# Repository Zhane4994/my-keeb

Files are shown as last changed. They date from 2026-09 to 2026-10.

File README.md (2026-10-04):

I designed a mechanical keyboard from scratch with kicad pcb's and onshape cases. I also learned how to use the RMK firmware to create a functional keyboard. I did this project because I used to be into keyboards and I thought it would be super cool to not only learn more about how they work but how to design one.

Part I, PCB and Schematic design

Day 1 Hour 1

I’m currently working on this at lunch. I have no idea what I’m doing lmao just following the guide. I have a slight idea of what I want to make. I am going to make it a 75% keyboard with a lcd screen and a knob. I just found out it’s supposedly due in a month golly. LOCK IN. This is my inspiration
nmpc-yunzii-AL80-silver-mechanical-keyboard-2059385894

Day 1 Hour 2

Just got back from school. I’ll be working on this for the next few days hopefully I’m able to get to the coding soon.


Just finished up the schematic matrices mostly.
Screenshot 2026-09-10 at 7 05 09 PM

Just finished up the Schematic matrices

Day 1 Hour 3

Screenshot 2026-09-10 at 7 27 56 PM

WOW. I’ve made up quite a bit of progress already and I’ve already thought of an idea of what I want my keyboard to be like. 1st, I want the entire keyboard to be a normal keyboard with no special shapes and a screen above the arrow keys. Now I’ve begun to create my PCB design.

Day 1 Hour 4&5

I spend 2 hours working on the PCB. I had to restart because I messed up the schematic somehow and it took me a bit to get the layout of the keyboard right. 
Screenshot 2026-09-10 at 11 40 44 PM

Day 1 Hour 6

I’ve just spent one hour on just wiring alone. This is super time consuming
Screenshot 2026-09-11 at 7 28 20 PM

Day 2 Hour 7&8

I’ve spent a while just working on moving stuff around according to the DRC as I had some issues. I also added a Rotary encoder and a OLED screen. I forgot to screenshot yesterday so this is my finished PCB now. I had to rewire a bunch of stuff and the PCB is packed and there isn’t much room.

Day 2 Hour 9

I just began to make my case. It actually took me so long to find out how to get the bom.cvs files
Screenshot 2026-09-11 at 11 09 13 PM

Day 2 Hour 10&11

Spent an hour creating the bottom half of my keyboard case and beginning to map out the key’s
Screenshot 2026-09-12 at 11 47 04 PM

I got through my process and realized that the tab, caps lock, shift, and control keys probably won’t work as I just randomly placed them. This is going to backtrack me all the way to a non wired PCB. Which will be annoying but I think it will be worth it just to get a keycap set that will actually look good on it.

Day 3 Hour 12

I spend this hour mostly asking ai how a led matrix works and if its possible with the pico its actually so bad but now I’m beginning to create the matrix and fixed using the normal GND pin instead of the AGND pin.


Day 3 Hour 13

Spent one hour creating a LED matrix and create the PCB
Screenshot 2026-09-13 at 7 27 45 PM

Day 4 Hour 14

I have spend today so far asking ai what to do about my capacitor situation because the ones I found on Aliexpress don’t have measurements of how apart the legs are and I didn’t think of just bending them if they are too close together so I’m just going to use radial 5mm 
Screenshot 2026-09-14 at 4 22 03 PM

Completed the key switch placement

Day 4 Hour 15&16

Screenshot 2026-09-14 at 7 28 04 PM

JEEZ. This actually took so long. I ended up taking 2 hours just to put in the diodes as well as all the LED in the right position. And I’m just starting wiring. This is going to be super hard and thanks to MD for letting me go off his keyboard as a reference point.

Day 5 Hour 17

Screenshot 2026-09-15 at 6 12 45 PM

So I just found out that I need to set the footprint to a different one for hot swap sockets so now I have to redo all the placements again

Day 5 Hour 18

Screenshot 2026-09-15 at 10 32 31 PM

While looking through the examples in slack, I found out that I don’t actually have enough space for a plate between the pcb and the top of the switches thanks to the pico 😡. Also someone told me that the LED’s actually should be on the bottom layer. AFTER I WIRED THEM ALL. So great I think it will be a lot easier to just straight up restart again 😡

Day 6 Hour 19

Screenshot 2026-09-16 at 5 32 16 PM

I’ve spent today wiring out the PCB. It’s super complicated as I flipped the pico to the back and have to switch the pin locations on the schematic.

Day 7 Hour 20

Screenshot 2026-09-20 at 6 13 34 PM

Pretty much finished my wiring. I took a forced break from my dad yesterday so lost some time there. I will try to complete by Wednesday or at least get to firmware.

Day 7 Hour 21

I’ve finished my PCB and tweaked it halfway into the case design because I realized the resistor placement is not optimal(look up above. I wanted to do a gasket mount by making the inside of the case be under the pcb by 3 mm but a resistor and capacitor would be in the way and I think it would just be better to move them)
I also began my case design so here’s part II
Part II, Case design

Day 9 Hour 22-25

It’s been a couple of days. I forgot to document my process but I’ve been using guides and references and I’ve taken about 3 hours to complete my case.
Screenshot 2026-09-25 at 6 41 36 PM

Day 10 Hour 26

Today, I’ve spent about an hour. Brainstorming and thinking of ideas of how to snap fit the 2 housing parts together and I’ve come up with an idea. Once side will have holes that the top housing can go into with tabs




And on the part of the case away from the user, there will be a notch in the base and a tab that will slide into it
Screenshot 2026-09-26 at 2 42 32 PM



Also It’s a triangle just so its a bit easier to take off but won’t come off just with use.

Screenshot 2026-09-26 at 3 53 06 PM

Completed Case
Part 3, Firmware
Day 11 Hour 27-29
I've spend almost 2 hours looking around the docs and figuring out how this works. The docs were pretty confusing because i have no clue what they are talking about lol
Screenshot 2026-09-26 at 3 53 06 PM
And that is my keyboard complete. I have 2 days left so i'm going to submit asap!
Screenshot 2026-10-02 at 9 41 14 PM

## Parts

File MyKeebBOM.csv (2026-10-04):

Reference | Qty | Value | DNP | Footprint | Datasheet | "Vendor" | "CAD" | "USD"
C1,C3,C4,C5,C6,C7,C8,C9,C10,C11 | 10 | 100 nF |  | Capacitor_THT:C_Radial_D5.0mm_H5.0mm_P2.00mm |  | https://www.aliexpress.com/item/1005005691676032.html
C2 | 1 | 470 uF |  | Capacitor_THT:C_Radial_D5.0mm_H5.0mm_P2.00mm |  | https://www.aliexpress.com/item/1005005945721276.html
R1 | 1 | 330 |  | Resistor_THT:R_Axial_DIN0207_L6.3mm_D2.5mm_P10.16mm_Horizontal |  | https://www.aliexpress.com/item/1005002994755806.html
S1 | 1 | 6.25 |  | PCM_marbastlib-mx:STAB_MX_P_6.25u |  | https://www.gateron.com/products/gateron-pcb-mounted-stabilizer?VariantsId=10538 | 8.54
S2 | 1 | 2.25 |  | PCM_marbastlib-mx:STAB_MX_P_2.25u |  | https://www.gateron.com/products/gateron-pcb-mounted-stabilizer?VariantsId=10538 | 8.54
S3 | 1 | 2.75 |  | PCM_marbastlib-mx:STAB_MX_2.75u |  | https://www.gateron.com/products/gateron-pcb-mounted-stabilizer?VariantsId=10538 | 8.54
S4 | 1 | 2.25 |  | PCM_marbastlib-mx:STAB_MX_2.25u |  | https://www.gateron.com/products/gateron-pcb-mounted-stabilizer?VariantsId=10538 | 8.54
S5 | 1 | 2 |  | PCM_marbastlib-mx:STAB_MX_2u |  | https://www.gateron.com/products/gateron-pcb-mounted-stabilizer?VariantsId=10538 | 8.54
SW1,SW2,SW3,SW4,SW5,SW6,SW7,SW8,SW9,SW10,SW11,SW12,SW13,SW14,SW15,SW16,SW17,SW18,SW19,SW20,SW21,SW22,SW23,SW24,SW25,SW26,SW27,SW29,SW30,SW31,SW32,SW33,SW34,SW35,SW36,SW37,SW38,SW39,SW40,SW43,SW44,SW45,SW46,SW47,SW48,SW49,SW50,SW51,SW52,SW53,SW54,SW55,SW56,SW57,SW58,SW59,SW60,SW61,SW62,SW63,SW64,SW65,SW66,SW67,SW71,SW74,SW75,SW76 | 68 | SW_Push |  | PCM_marbastlib-mx:SW_MX_HS_KS-2P02B01-01_1u |  | https://www.gateron.com/products/gateron-ks-3-milky-pro-switch-set?VariantsId=10404 | 40.7
SW28,SW41 | 2 | SW_Push |  | PCM_marbastlib-mx:SW_MX_HS_KS-2P02B01-01_1.5u |  | https://www.gateron.com/products/gateron-ks-3-milky-pro-switch-set?VariantsId=10404 | 40.7
SW42 | 1 | SW_Push |  | PCM_marbastlib-mx:SW_MX_HS_KS-2P02B01-01_1.75u |  | https://www.gateron.com/products/gateron-ks-3-milky-pro-switch-set?VariantsId=10404 | 40.7
SW68,SW69,SW70,SW72,SW73 | 5 | SW_Push |  | PCM_marbastlib-mx:SW_MX_HS_KS-2P02B01-01_1.25u |  | https://www.gateron.com/products/gateron-ks-3-milky-pro-switch-set?VariantsId=10404 | 40.7
SW78 | 1 | RotaryEncoder_Switch |  | Rotary_Encoder:RotaryEncoder_Alps_EC11E-Switch_Vertical_H20mm_MountingHoles |  | https://www.digikey.ca/en/products/detail/alps-alpine/EC11E15244G1/21721550 | 7.69
D1,D2,D3,D4,D5,D6,D7,D8,D9,D10,D11,D12,D13,D14,D15,D16,D17,D18,D19,D20,D21,D22,D23,D24,D25,D26,D27,D28,D29,D30,D31,D32,D33,D34,D35,D36,D37,D38,D39,D40,D41,D42,D43,D44,D45,D46,D47,D48,D49,D50,D51,D52,D53,D54,D55,D56,D57,D58,D59,D60,D61,D62,D63,D64,D65,D66,D67,D68,D69,D70,D71,D72,D73,D74,D75,D76,D77 | 77 | 1N4148 |  | Diode_THT:D_DO-35_SOD27_P7.62mm_Horizontal | https://assets.nexperia.com/documents/data-sheet/1N4148_1N4448.pdf | https://www.aliexpress.com/item/1005009379098965.html
A1 | 1 | RaspberryPi_Pico |  | Module:RaspberryPi_Pico_Common_THT | https://datasheets.raspberrypi.com/pico/pico-datasheet.pdf | https://www.aliexpress.com/item/1005007385123930.html | 6.19
U1 | 1 | ER_OLEDM0.91_1x-I2C |  | Display:ER_OLEDM0.91_1x-I2C | https://www.buydisplay.com/download/manual/ER-OLEDM0.91-1_Datasheet.pdf | https://www.aliexpress.com/item/1005012376797588.html
D78,D79,D80,D81,D82,D83,D84,D85,D86,D87,D88,D89,D90,D91,D92,D93,D94,D95,D96,D97,D98,D99,D100,D101,D102,D103,D104,D105,D106,D107,D108,D109,D110,D111,D112,D113,D114,D115,D116,D117,D118,D119,D120,D121,D122,D123,D124,D125,D126,D127,D128,D129,D130,D131,D132,D133,D134,D135,D136,D137,D138,D139,D140,D141,D142,D143,D144,D145,D146,D147,D148,D149,D150,D151,D152,D153 | 76 | SK6812MINI-E |  | LED_SMD:LED_SK6812MINI-E_3.2x2.8mm_P1.5mm_ReverseMount | https://www.lcsc.com/datasheet/C5149201.pdf | https://www.lcsc.com/product-detail/C5149201.html?s_z=n_SK6812%2520MINI-E | Not Listed | 5.2
SW1,SW2,SW3,SW4,SW5,SW6,SW7,SW8,SW9,SW10,SW11,SW12,SW13,SW14,SW15,SW16,SW17,SW18,SW19,SW20,SW21,SW22,SW23,SW24,SW25,SW26,SW27,SW29,SW30,SW31,SW32,SW33,SW34,SW35,SW36,SW37,SW38,SW39,SW40,SW43,SW44,SW45,SW46,SW47,SW48,SW49,SW50,SW51,SW52,SW53,SW54,SW55,SW56,SW57,SW58,SW59,SW60,SW61,SW62,SW63,SW64,SW65,SW66,SW67,SW71,SW74,SW75,SW76,SW28,SW41,SW42,SW68,SW69,SW70,SW72,SW73 | 76 | Hotswap Sockets |  |  |  | https://www.gateron.com/products/gateron-hot-swap-pcb-socket?VariantsId=10171 | 15.66
SW1,SW2,SW3,SW4,SW5,SW6,SW7,SW8,SW9,SW10,SW11,SW12,SW13,SW14,SW15,SW16,SW17,SW18,SW19,SW20,SW21,SW22,SW23,SW24,SW25,SW26,SW27,SW29,SW30,SW31,SW32,SW33,SW34,SW35,SW36,SW37,SW38,SW39,SW40,SW43,SW44,SW45,SW46,SW47,SW48,SW49,SW50,SW51,SW52,SW53,SW54,SW55,SW56,SW57,SW58,SW59,SW60,SW61,SW62,SW63,SW64,SW65,SW66,SW67,SW71,SW74,SW75,SW76,SW28,SW41,SW42,SW68,SW69,SW70,SW72,SW73 | 76 | KeyCaps |  |  |  | https://www.aliexpress.com/item/1005010591356090.html | 13

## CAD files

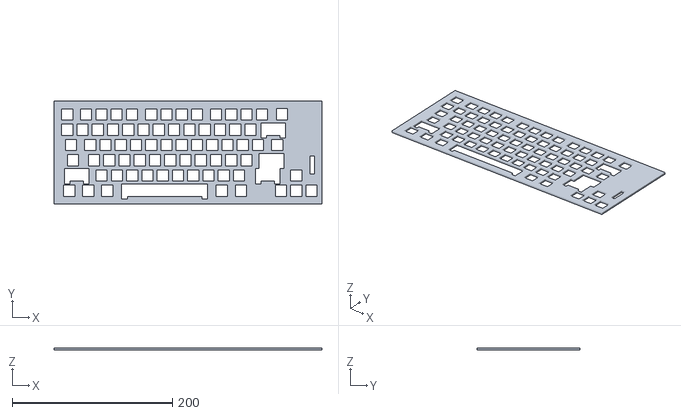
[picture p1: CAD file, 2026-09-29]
MyKeeb Case - Foam Plate(2).stl
334.5 x 128.7 x 2.50

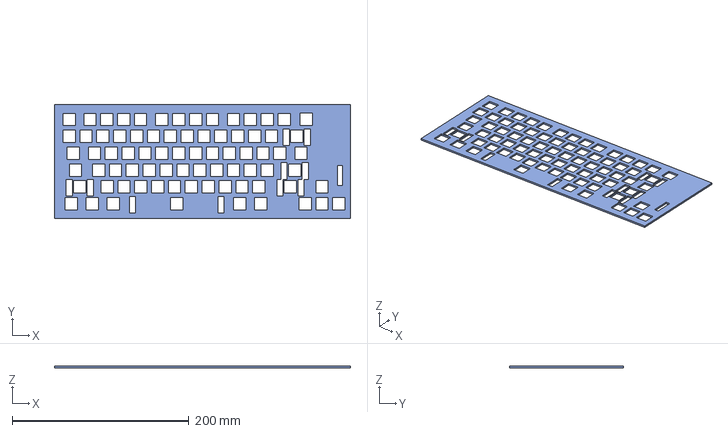
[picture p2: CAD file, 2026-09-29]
STEP files/MyKeeb Case - Plate.step
334.5 x 128.8 x 2.00 mm

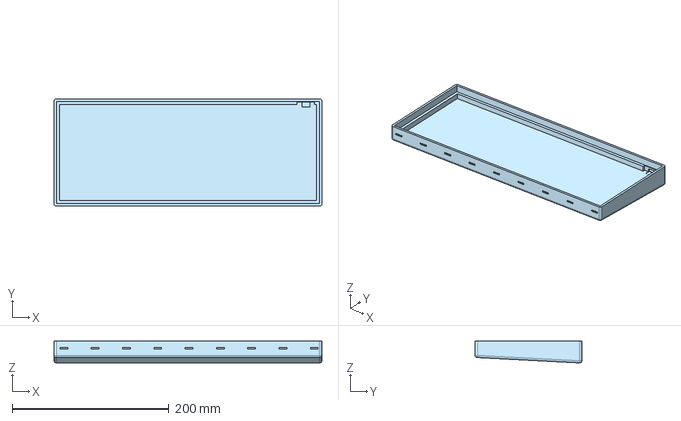
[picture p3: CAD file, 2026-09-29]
STEP files/MyKeeb Case - Base Housing.step
342.5 x 136.8 x 28.0 mm

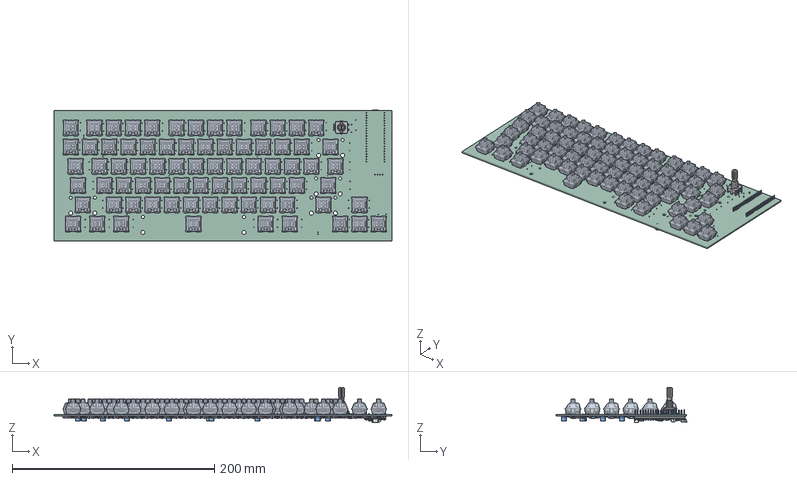
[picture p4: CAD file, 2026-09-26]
MyKeeb.step
334.5 x 129.2 x 34.8 mm
EC11_Rotary_Encoder_Switched
C_Radial_D50mm_H50mm_P200mm x 11
Pin1 x 76
Pin2 x 76
Pin3 x 76
Pin4 x 76
HS_gat_mx v8 x 76
RD-05E35zu19 x 76
D_DO-35_SOD27_P7.62mm_Horizontal x 77
RaspberryPi_Pico_H_Module_KiCad
RaspberryPi_Pico_Header_DIP-40_H2.54mm_KiCad
R_Axial_DIN0207_L63mm_D25mm_P1016mm_Horizontal
MyKeeb_PCB

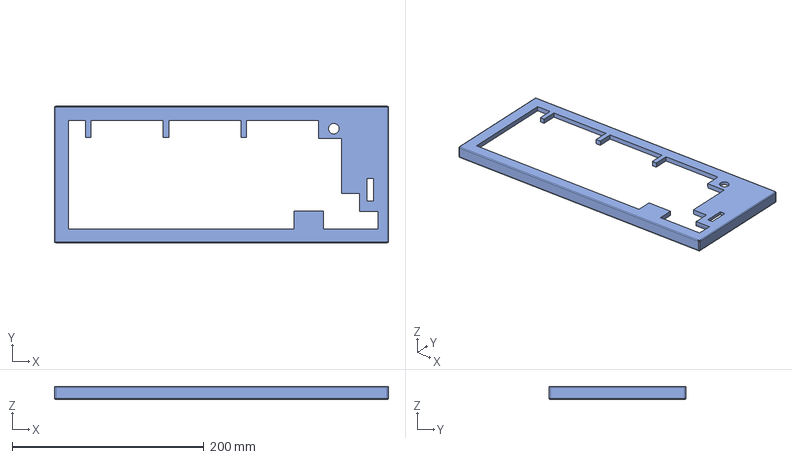
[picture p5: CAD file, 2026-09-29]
STEP files/MyKeeb Case - Top Housing.step
348.5 x 142.8 x 14.0 mm

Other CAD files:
MyKeeb Case - Foam Plate(1).step
STEP files/MyKeeb Case - Foam Plate.step
MyKeeb Case - Plate(1).stl
STL files/MyKeeb Case - Base Housing.stl
STL files/MyKeeb Case - Plate.stl
STL files/MyKeeb Case - Top Housing.stl

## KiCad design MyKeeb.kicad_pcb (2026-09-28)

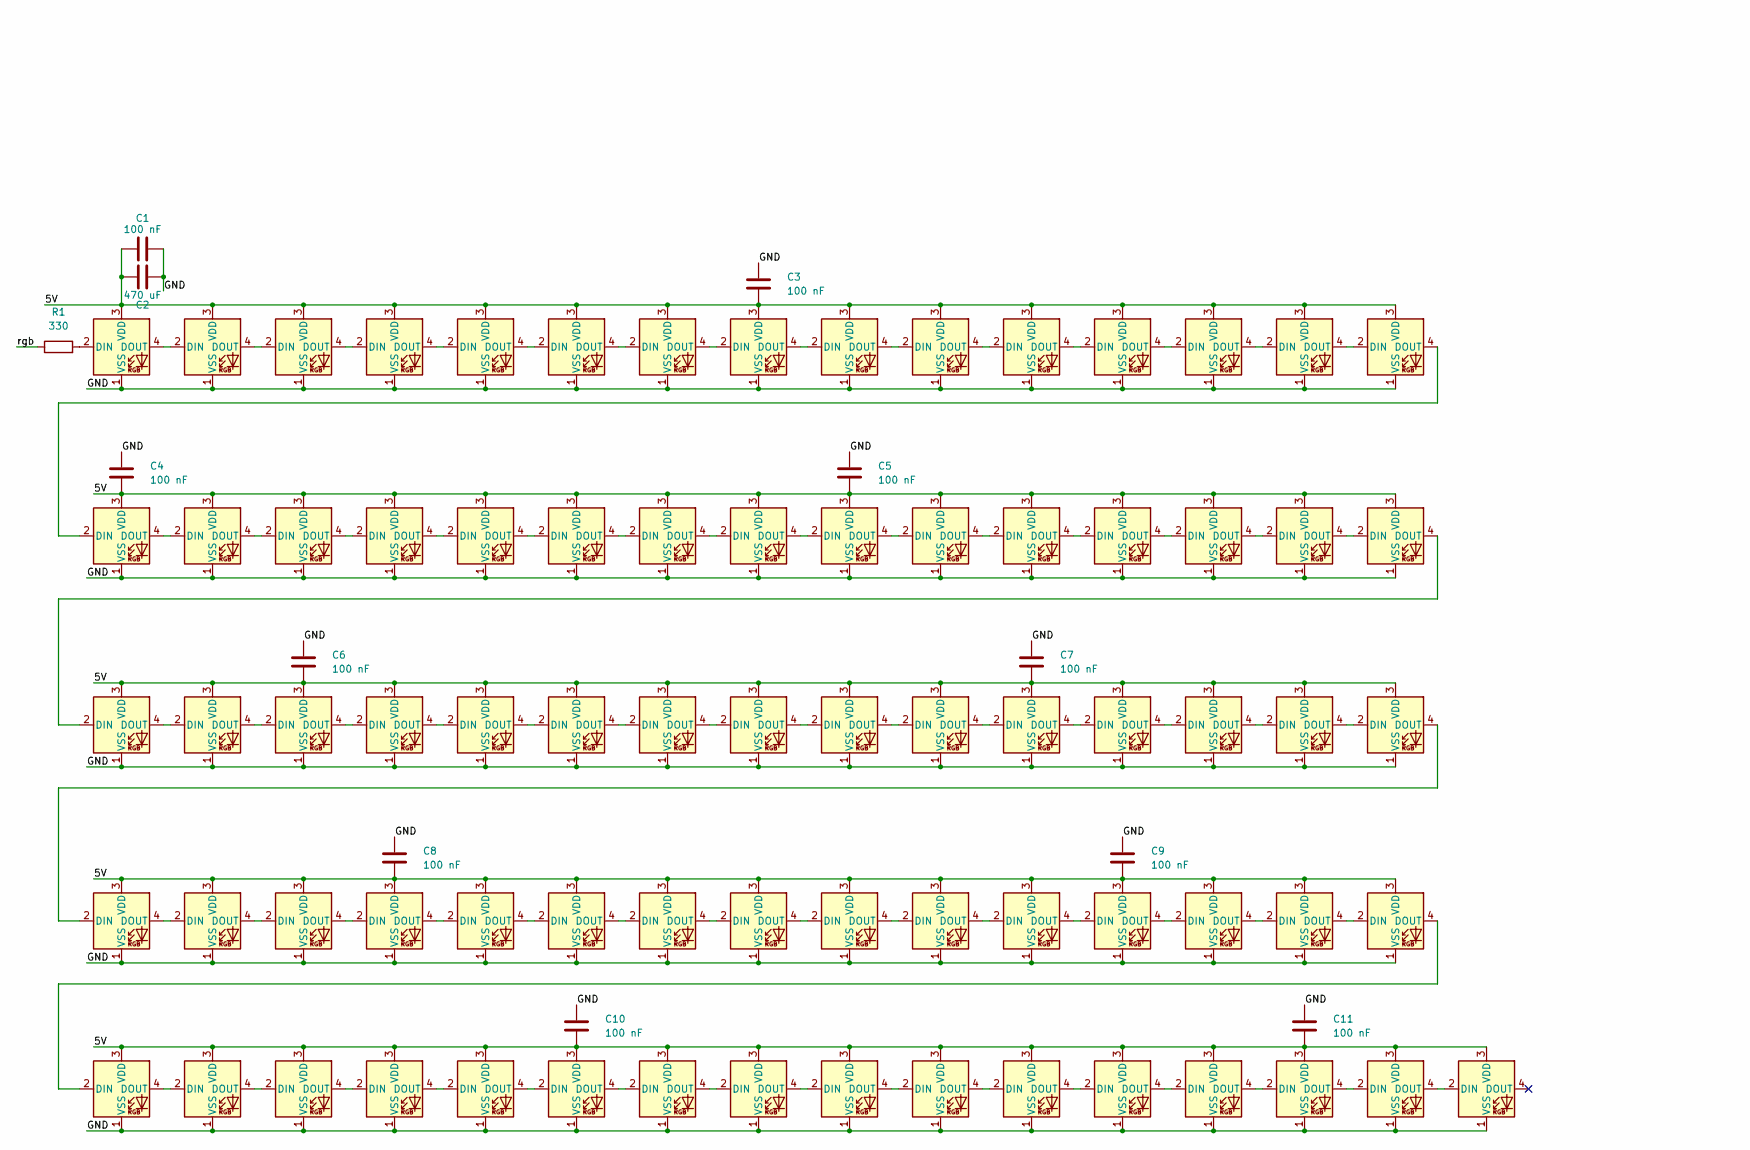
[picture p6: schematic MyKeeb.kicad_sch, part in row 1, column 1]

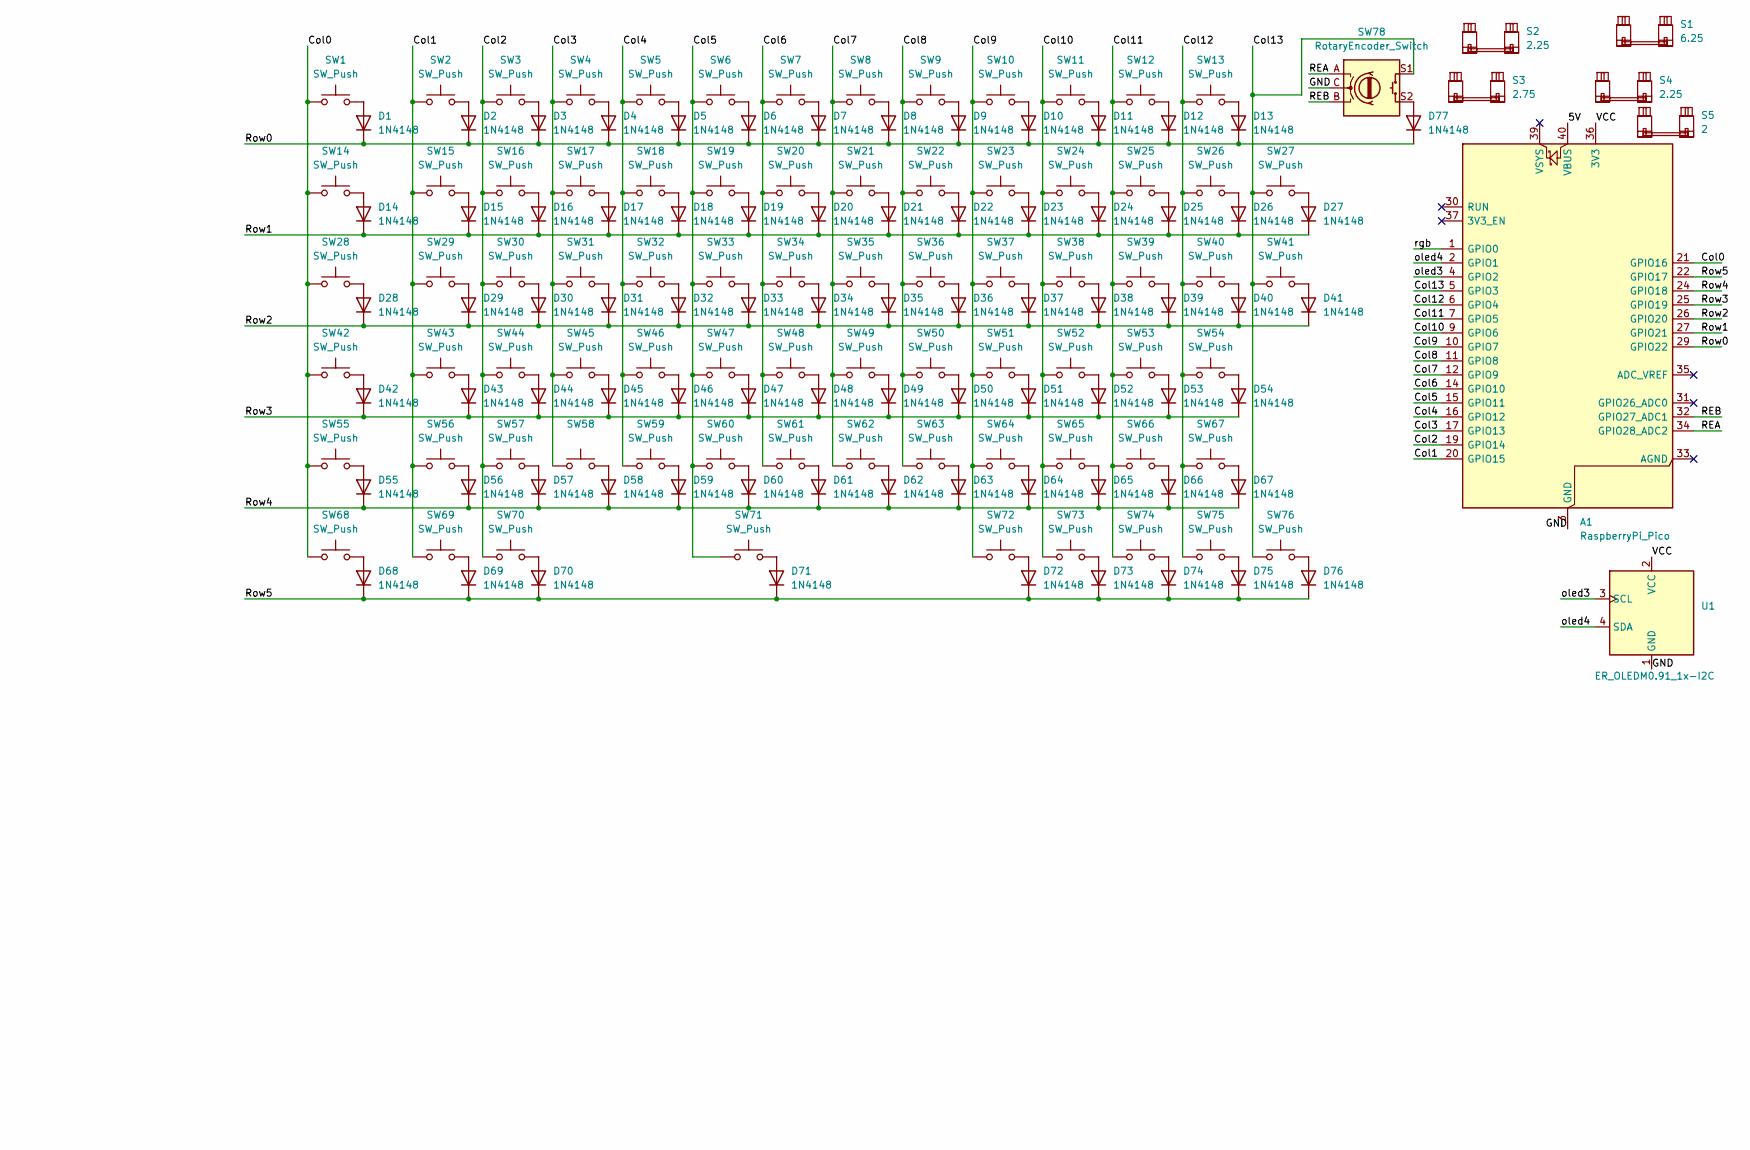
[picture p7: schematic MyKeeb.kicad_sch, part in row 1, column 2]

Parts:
A1: RaspberryPi_Pico; RaspberryPi_Pico_Common_THT
C1, C3, C4, C5, C6, C7, C8, C9, C10, C11: 100 nF; C_Radial_D5.0mm_H5.0mm_P2.00mm
C2: 470 uF; C_Radial_D5.0mm_H5.0mm_P2.00mm
D1, D2, D3, D4, D5, D6, D7, D8, D9, D10, D11, D12, D13, D14, D15, D16, D17, D18, D19, D20, D21, D22, D23, D24, D25, D26, D27, D28, D29, D30, D31, D32, D33, D34, D35, D36, D37, D38, D39, D40, D41, D42, D43, D44, D45, D46, D47, D48, D49, D50, D51, D52, D53, D54, D55, D56, D57, D58, D59, D60, D61, D62, D63, D64, D65, D66, D67, D68, D69, D70, D71, D72, D73, D74, D75, D76, D77: 1N4148; D_DO-35_SOD27_P7.62mm_Horizontal
D78, D79, D80, D81, D82, D83, D84, D85, D86, D87, D88, D89, D90, D91, D92, D93, D94, D95, D96, D97, D98, D99, D100, D101, D102, D103, D104, D105, D106, D107, D108, D109, D110, D111, D112, D113, D114, D115, D116, D117, D118, D119, D120, D121, D122, D123, D124, D125, D126, D127, D128, D129, D130, D131, D132, D133, D134, D135, D136, D137, D138, D139, D140, D141, D142, D143, D144, D145, D146, D147, D148, D149, D150, D151, D152, D153: SK6812MINI-E; LED_SK6812MINI-E_3.2x2.8mm_P1.5mm_ReverseMount
R1: 330; R_Axial_DIN0207_L6.3mm_D2.5mm_P10.16mm_Horizontal
S1: 6.25; STAB_MX_P_6.25u
S2: 2.25; STAB_MX_P_2.25u
S3: 2.75; STAB_MX_2.75u
S4: 2.25; STAB_MX_2.25u
S5: 2; STAB_MX_2u
SW1, SW2, SW3, SW4, SW5, SW6, SW7, SW8, SW9, SW10, SW11, SW12, SW13, SW14, SW15, SW16, SW17, SW18, SW19, SW20, SW21, SW22, SW23, SW24, SW25, SW26, SW27, SW29, SW30, SW31, SW32, SW33, SW34, SW35, SW36, SW37, SW38, SW39, SW40, SW43, SW44, SW45, SW46, SW47, SW48, SW49, SW50, SW51, SW52, SW53, SW54, SW55, SW56, SW57, SW58, SW59, SW60, SW61, SW62, SW63, SW64, SW65, SW66, SW67, SW71, SW74, SW75, SW76: SW_Push; SW_MX_HS_KS-2P02B01-01_1u
SW28, SW41: SW_Push; SW_MX_HS_KS-2P02B01-01_1.5u
SW42: SW_Push; SW_MX_HS_KS-2P02B01-01_1.75u
SW68, SW69, SW70, SW72, SW73: SW_Push; SW_MX_HS_KS-2P02B01-01_1.25u
SW78: RotaryEncoder_Switch; RotaryEncoder_Alps_EC11E-Switch_Vertical_H20mm_MountingHoles
U1: ER_OLEDM0.91_1x-I2C

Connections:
/5V: A1.40 (VBUS), C1.1, C2.1, C3.2, C4.2, C5.2, C6.2, C7.2, C8.2, C9.2, C10.2, C11.2, D78.3 (VDD), D79.3 (VDD), D80.3 (VDD), D81.3 (VDD), D82.3 (VDD), D83.3 (VDD), D84.3 (VDD), D85.3 (VDD), D86.3 (VDD), D87.3 (VDD), D88.3 (VDD), D89.3 (VDD), D90.3 (VDD), D91.3 (VDD), D92.3 (VDD), D93.3 (VDD), D94.3 (VDD), D95.3 (VDD), D96.3 (VDD), D97.3 (VDD), D98.3 (VDD), D99.3 (VDD), D100.3 (VDD), D101.3 (VDD), D102.3 (VDD), D103.3 (VDD), D104.3 (VDD), D105.3 (VDD), D106.3 (VDD), D107.3 (VDD), D108.3 (VDD), D109.3 (VDD), D110.3 (VDD), D111.3 (VDD), D112.3 (VDD), D113.3 (VDD), D114.3 (VDD), D115.3 (VDD), D116.3 (VDD), D117.3 (VDD), D118.3 (VDD), D119.3 (VDD), D120.3 (VDD), D121.3 (VDD), D122.3 (VDD), D123.3 (VDD), D124.3 (VDD), D125.3 (VDD), D126.3 (VDD), D127.3 (VDD), D128.3 (VDD), D129.3 (VDD), D130.3 (VDD), D131.3 (VDD), D132.3 (VDD), D133.3 (VDD), D134.3 (VDD), D135.3 (VDD), D136.3 (VDD), D137.3 (VDD), D138.3 (VDD), D139.3 (VDD), D140.3 (VDD), D141.3 (VDD), D142.3 (VDD), D143.3 (VDD), D144.3 (VDD), D145.3 (VDD), D146.3 (VDD), D147.3 (VDD), D148.3 (VDD), D149.3 (VDD), D150.3 (VDD), D151.3 (VDD), D152.3 (VDD), D153.3 (VDD)
/Col0: A1.21 (GPIO16), SW1.1, SW14.1, SW28.1, SW42.1, SW55.1, SW68.1
/Col1: A1.20 (GPIO15), SW2.1, SW15.1, SW29.1, SW43.1, SW56.1, SW69.1
/Col2: A1.19 (GPIO14), SW3.1, SW16.1, SW30.1, SW44.1, SW57.1, SW70.1
/Col3: A1.17 (GPIO13), SW4.1, SW17.1, SW31.1, SW45.1, SW58.1
/Col4: A1.16 (GPIO12), SW5.1, SW18.1, SW32.1, SW46.1, SW59.1
/Col5: A1.15 (GPIO11), SW6.1, SW19.1, SW33.1, SW47.1, SW60.1, SW71.1
/Col6: A1.14 (GPIO10), SW7.1, SW20.1, SW34.1, SW48.1, SW61.1
/Col7: A1.12 (GPIO9), SW8.1, SW21.1, SW35.1, SW49.1, SW62.1
/Col8: A1.11 (GPIO8), SW9.1, SW22.1, SW36.1, SW50.1, SW63.1
/Col9: A1.10 (GPIO7), SW10.1, SW23.1, SW37.1, SW51.1, SW64.1, SW72.1
/Col10: A1.9 (GPIO6), SW11.1, SW24.1, SW38.1, SW52.1, SW65.1, SW73.1
/Col11: A1.7 (GPIO5), SW12.1, SW25.1, SW39.1, SW53.1, SW66.1, SW74.1
/Col12: A1.6 (GPIO4), SW13.1, SW26.1, SW40.1, SW54.1, SW67.1, SW75.1
/Col13: A1.5 (GPIO3), SW27.1, SW41.1, SW76.1, SW78.S1
/GND: A1.3 (GND), A1.8 (GND), A1.13 (GND), A1.18 (GND), A1.23 (GND), A1.28 (GND), A1.38 (GND), C1.2, C2.2, C3.1, C4.1, C5.1, C6.1, C7.1, C8.1, C9.1, C10.1, C11.1, D78.1 (VSS), D79.1 (VSS), D80.1 (VSS), D81.1 (VSS), D82.1 (VSS), D83.1 (VSS), D84.1 (VSS), D85.1 (VSS), D86.1 (VSS), D87.1 (VSS), D88.1 (VSS), D89.1 (VSS), D90.1 (VSS), D91.1 (VSS), D92.1 (VSS), D93.1 (VSS), D94.1 (VSS), D95.1 (VSS), D96.1 (VSS), D97.1 (VSS), D98.1 (VSS), D99.1 (VSS), D100.1 (VSS), D101.1 (VSS), D102.1 (VSS), D103.1 (VSS), D104.1 (VSS), D105.1 (VSS), D106.1 (VSS), D107.1 (VSS), D108.1 (VSS), D109.1 (VSS), D110.1 (VSS), D111.1 (VSS), D112.1 (VSS), D113.1 (VSS), D114.1 (VSS), D115.1 (VSS), D116.1 (VSS), D117.1 (VSS), D118.1 (VSS), D119.1 (VSS), D120.1 (VSS), D121.1 (VSS), D122.1 (VSS), D123.1 (VSS), D124.1 (VSS), D125.1 (VSS), D126.1 (VSS), D127.1 (VSS), D128.1 (VSS), D129.1 (VSS), D130.1 (VSS), D131.1 (VSS), D132.1 (VSS), D133.1 (VSS), D134.1 (VSS), D135.1 (VSS), D136.1 (VSS), D137.1 (VSS), D138.1 (VSS), D139.1 (VSS), D140.1 (VSS), D141.1 (VSS), D142.1 (VSS), D143.1 (VSS), D144.1 (VSS), D145.1 (VSS), D146.1 (VSS), D147.1 (VSS), D148.1 (VSS), D149.1 (VSS), D150.1 (VSS), D151.1 (VSS), D152.1 (VSS), D153.1 (VSS), SW78.C, U1.1 (GND)
/REA: A1.34 (GPIO28_ADC2), SW78.A
/REB: A1.32 (GPIO27_ADC1), SW78.B
/Row0: A1.29 (GPIO22), D1.1 (K), D2.1 (K), D3.1 (K), D4.1 (K), D5.1 (K), D6.1 (K), D7.1 (K), D8.1 (K), D9.1 (K), D10.1 (K), D11.1 (K), D12.1 (K), D13.1 (K), D77.1 (K)
/Row1: A1.27 (GPIO21), D14.1 (K), D15.1 (K), D16.1 (K), D17.1 (K), D18.1 (K), D19.1 (K), D20.1 (K), D21.1 (K), D22.1 (K), D23.1 (K), D24.1 (K), D25.1 (K), D26.1 (K), D27.1 (K)
/Row2: A1.26 (GPIO20), D28.1 (K), D29.1 (K), D30.1 (K), D31.1 (K), D32.1 (K), D33.1 (K), D34.1 (K), D35.1 (K), D36.1 (K), D37.1 (K), D38.1 (K), D39.1 (K), D40.1 (K), D41.1 (K)
/Row3: A1.25 (GPIO19), D42.1 (K), D43.1 (K), D44.1 (K), D45.1 (K), D46.1 (K), D47.1 (K), D48.1 (K), D49.1 (K), D50.1 (K), D51.1 (K), D52.1 (K), D53.1 (K), D54.1 (K)
/Row4: A1.24 (GPIO18), D55.1 (K), D56.1 (K), D57.1 (K), D58.1 (K), D59.1 (K), D60.1 (K), D61.1 (K), D62.1 (K), D63.1 (K), D64.1 (K), D65.1 (K), D66.1 (K), D67.1 (K)
/Row5: A1.22 (GPIO17), D68.1 (K), D69.1 (K), D70.1 (K), D71.1 (K), D72.1 (K), D73.1 (K), D74.1 (K), D75.1 (K), D76.1 (K)
/VCC: A1.36 (3V3), U1.2 (VCC)
/oled3: A1.4 (GPIO2), U1.3 (SCL)
/oled4: A1.2 (GPIO1), U1.4 (SDA)
/rgb: A1.1 (GPIO0), R1.1
unnamed: D1.2 (A), SW1.2
unnamed: D2.2 (A), SW2.2
unnamed: D3.2 (A), SW3.2
unnamed: D4.2 (A), SW4.2
unnamed: D5.2 (A), SW5.2
unnamed: D6.2 (A), SW6.2
unnamed: D7.2 (A), SW7.2
unnamed: D8.2 (A), SW8.2
unnamed: D9.2 (A), SW9.2
unnamed: D10.2 (A), SW10.2
unnamed: D11.2 (A), SW11.2
unnamed: D12.2 (A), SW12.2
unnamed: D13.2 (A), SW13.2
unnamed: D14.2 (A), SW14.2
unnamed: D15.2 (A), SW15.2
unnamed: D16.2 (A), SW16.2
unnamed: D17.2 (A), SW17.2
unnamed: D18.2 (A), SW18.2
unnamed: D19.2 (A), SW19.2
unnamed: D20.2 (A), SW20.2
unnamed: D21.2 (A), SW21.2
unnamed: D22.2 (A), SW22.2
unnamed: D23.2 (A), SW23.2
unnamed: D24.2 (A), SW24.2
unnamed: D25.2 (A), SW25.2
unnamed: D26.2 (A), SW26.2
unnamed: D27.2 (A), SW27.2
unnamed: D28.2 (A), SW28.2
unnamed: D29.2 (A), SW29.2
unnamed: D30.2 (A), SW30.2
unnamed: D31.2 (A), SW31.2
unnamed: D32.2 (A), SW32.2
unnamed: D33.2 (A), SW33.2
unnamed: D34.2 (A), SW34.2
unnamed: D35.2 (A), SW35.2
unnamed: D36.2 (A), SW36.2
unnamed: D37.2 (A), SW37.2
unnamed: D38.2 (A), SW38.2
unnamed: D39.2 (A), SW39.2
unnamed: D40.2 (A), SW40.2
unnamed: D41.2 (A), SW41.2
unnamed: D42.2 (A), SW42.2
unnamed: D43.2 (A), SW43.2
unnamed: D44.2 (A), SW44.2
unnamed: D45.2 (A), SW45.2
unnamed: D46.2 (A), SW46.2
unnamed: D47.2 (A), SW47.2
unnamed: D48.2 (A), SW48.2
unnamed: D49.2 (A), SW49.2
unnamed: D50.2 (A), SW50.2
unnamed: D51.2 (A), SW51.2
unnamed: D52.2 (A), SW52.2
unnamed: D53.2 (A), SW53.2
unnamed: D54.2 (A), SW54.2
unnamed: D55.2 (A), SW55.2
unnamed: D56.2 (A), SW56.2
unnamed: D57.2 (A), SW57.2
unnamed: D58.2 (A), SW58.2
unnamed: D59.2 (A), SW59.2
unnamed: D60.2 (A), SW60.2
unnamed: D61.2 (A), SW61.2
unnamed: D62.2 (A), SW62.2
unnamed: D63.2 (A), SW63.2
unnamed: D64.2 (A), SW64.2
unnamed: D65.2 (A), SW65.2
unnamed: D66.2 (A), SW66.2
unnamed: D67.2 (A), SW67.2
unnamed: D68.2 (A), SW68.2
unnamed: D69.2 (A), SW69.2
unnamed: D70.2 (A), SW70.2
unnamed: D71.2 (A), SW71.2
unnamed: D72.2 (A), SW72.2
unnamed: D73.2 (A), SW73.2
unnamed: D74.2 (A), SW74.2
unnamed: D75.2 (A), SW75.2
unnamed: D76.2 (A), SW76.2
unnamed: D77.2 (A), SW78.S2
unnamed: D78.2 (DIN), R1.2
unnamed: D78.4 (DOUT), D79.2 (DIN)
unnamed: D79.4 (DOUT), D80.2 (DIN)
unnamed: D80.4 (DOUT), D81.2 (DIN)
unnamed: D81.4 (DOUT), D82.2 (DIN)
unnamed: D82.4 (DOUT), D83.2 (DIN)
unnamed: D83.4 (DOUT), D84.2 (DIN)
unnamed: D84.4 (DOUT), D85.2 (DIN)
unnamed: D85.4 (DOUT), D86.2 (DIN)
unnamed: D86.4 (DOUT), D87.2 (DIN)
unnamed: D87.4 (DOUT), D88.2 (DIN)
unnamed: D88.4 (DOUT), D89.2 (DIN)
unnamed: D89.4 (DOUT), D90.2 (DIN)
unnamed: D90.4 (DOUT), D91.2 (DIN)
unnamed: D91.4 (DOUT), D92.2 (DIN)
unnamed: D92.4 (DOUT), D93.2 (DIN)
unnamed: D93.4 (DOUT), D94.2 (DIN)
unnamed: D94.4 (DOUT), D95.2 (DIN)
unnamed: D95.4 (DOUT), D96.2 (DIN)
unnamed: D96.4 (DOUT), D97.2 (DIN)
unnamed: D97.4 (DOUT), D98.2 (DIN)
unnamed: D98.4 (DOUT), D99.2 (DIN)
unnamed: D99.4 (DOUT), D100.2 (DIN)
unnamed: D100.4 (DOUT), D101.2 (DIN)
unnamed: D101.4 (DOUT), D102.2 (DIN)
unnamed: D102.4 (DOUT), D103.2 (DIN)
unnamed: D103.4 (DOUT), D104.2 (DIN)
unnamed: D104.4 (DOUT), D105.2 (DIN)
unnamed: D105.4 (DOUT), D106.2 (DIN)
unnamed: D106.4 (DOUT), D107.2 (DIN)
unnamed: D107.4 (DOUT), D108.2 (DIN)
unnamed: D108.4 (DOUT), D109.2 (DIN)
unnamed: D109.4 (DOUT), D110.2 (DIN)
unnamed: D110.4 (DOUT), D111.2 (DIN)
unnamed: D111.4 (DOUT), D112.2 (DIN)
unnamed: D112.4 (DOUT), D113.2 (DIN)
unnamed: D113.4 (DOUT), D114.2 (DIN)
unnamed: D114.4 (DOUT), D115.2 (DIN)
unnamed: D115.4 (DOUT), D116.2 (DIN)
unnamed: D116.4 (DOUT), D117.2 (DIN)
unnamed: D117.4 (DOUT), D118.2 (DIN)
unnamed: D118.4 (DOUT), D119.2 (DIN)
unnamed: D119.4 (DOUT), D120.2 (DIN)
unnamed: D120.4 (DOUT), D121.2 (DIN)
unnamed: D121.4 (DOUT), D122.2 (DIN)
unnamed: D122.4 (DOUT), D123.2 (DIN)
unnamed: D123.4 (DOUT), D124.2 (DIN)
unnamed: D124.4 (DOUT), D125.2 (DIN)
unnamed: D125.4 (DOUT), D126.2 (DIN)
unnamed: D126.4 (DOUT), D127.2 (DIN)
unnamed: D127.4 (DOUT), D128.2 (DIN)
unnamed: D128.4 (DOUT), D129.2 (DIN)
unnamed: D129.4 (DOUT), D130.2 (DIN)
unnamed: D130.4 (DOUT), D131.2 (DIN)
unnamed: D131.4 (DOUT), D132.2 (DIN)
unnamed: D132.4 (DOUT), D133.2 (DIN)
unnamed: D133.4 (DOUT), D134.2 (DIN)
unnamed: D134.4 (DOUT), D135.2 (DIN)
unnamed: D135.4 (DOUT), D136.2 (DIN)
unnamed: D136.4 (DOUT), D137.2 (DIN)
unnamed: D137.4 (DOUT), D138.2 (DIN)
unnamed: D138.4 (DOUT), D139.2 (DIN)
unnamed: D139.4 (DOUT), D140.2 (DIN)
unnamed: D140.4 (DOUT), D141.2 (DIN)
unnamed: D141.4 (DOUT), D142.2 (DIN)
unnamed: D142.4 (DOUT), D143.2 (DIN)
unnamed: D143.4 (DOUT), D144.2 (DIN)
unnamed: D144.4 (DOUT), D145.2 (DIN)
unnamed: D145.4 (DOUT), D146.2 (DIN)
unnamed: D146.4 (DOUT), D147.2 (DIN)
unnamed: D147.4 (DOUT), D148.2 (DIN)
unnamed: D148.4 (DOUT), D149.2 (DIN)
unnamed: D149.4 (DOUT), D150.2 (DIN)
unnamed: D150.4 (DOUT), D151.2 (DIN)
unnamed: D151.4 (DOUT), D152.2 (DIN)
unnamed: D152.4 (DOUT), D153.2 (DIN)

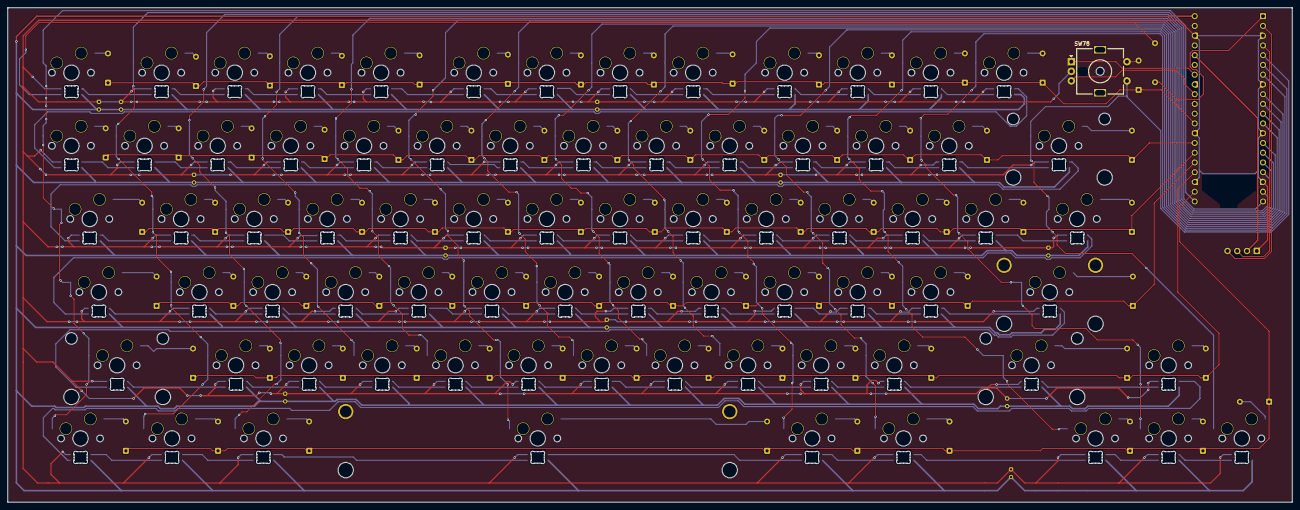
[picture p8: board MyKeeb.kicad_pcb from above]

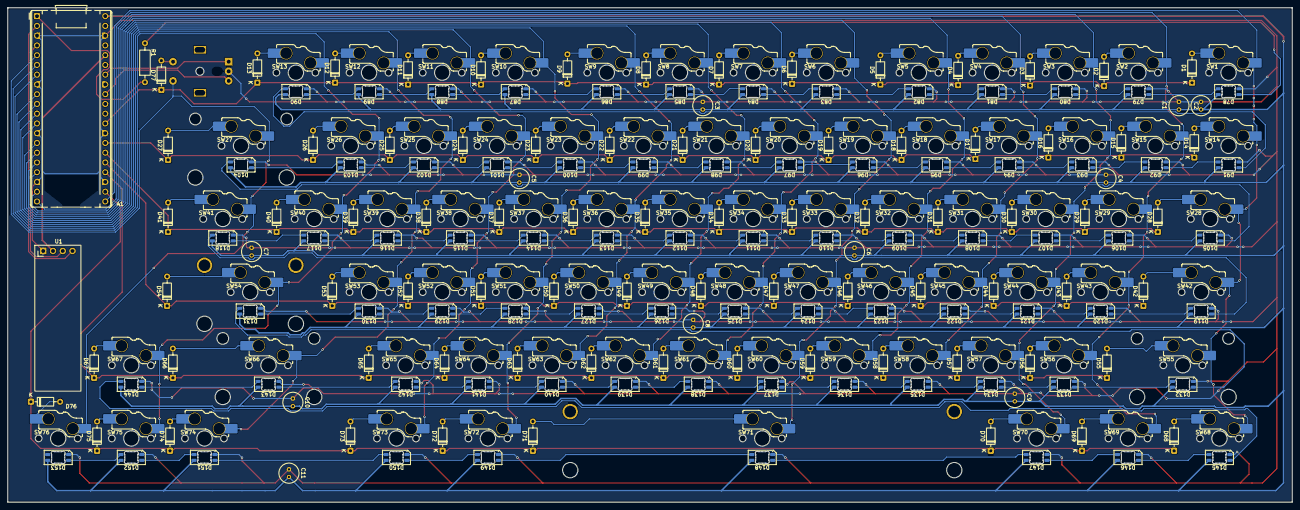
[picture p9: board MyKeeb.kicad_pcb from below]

Board: 2 copper layers, 334.5 x 128.8 mm, 249 parts (243 on the bottom side), 181 nets.

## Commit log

2026-09-20 Add MyKeebBOM.csv file
    [MyKeebBOM.csv]
2026-09-28 Rename MyKeeb Case - Foam Plate(1).stl to MyKeeb Case - Foam Plate.stl
    [MyKeeb Case - Foam Plate.stl]
2026-09-29 Update MyKeebBOM.csv with new components
    [MyKeebBOM.csv]
2026-09-29 Update hotswap sockets entry in MyKeebBOM.csv
    [MyKeebBOM.csv]
2026-09-29 Add datasheet links for stabilizer components
    Updated stabilizer entries with datasheet links.
    [MyKeebBOM.csv]
2026-09-29 Rename MyKeeb Case - Base Housing.step to STEP files/MyKeeb Case - Base Housing.step
    [MyKeeb Case - Base Housing.step]
2026-09-29 Rename MyKeeb Case - Foam Plate.step to STEP files/MyKeeb Case - Foam Plate.step
    [MyKeeb Case - Foam Plate.step]
2026-09-29 Rename MyKeeb Case - Plate.step to STEP files/MyKeeb Case - Plate.step
    [MyKeeb Case - Plate.step]
2026-09-29 Rename MyKeeb Case - Top Housing.step to STEP files/MyKeeb Case - Top Housing.step
    [MyKeeb Case - Top Housing.step]
2026-09-29 Rename MyKeeb Case - Base Housing.stl to STL fiels/MyKeeb Case - Base Housing.stl
    [MyKeeb Case - Base Housing.stl]
2026-09-29 Rename MyKeeb Case - Foam Plate.stl to STL files/MyKeeb Case - Foam Plate.stl
    [MyKeeb Case - Foam Plate.stl]
2026-09-29 Rename MyKeeb Case - Plate.stl to STL files/MyKeeb Case - Plate.stl
    [MyKeeb Case - Plate.stl]
2026-09-29 Rename MyKeeb Case - Top Housing.stl to STL files/MyKeeb Case - Top Housing.stl
    [MyKeeb Case - Top Housing.stl]
2026-09-29 Rename MyKeeb Case - Base Housing.stl to MyKeeb Case - Base Housing.stl
    [MyKeeb Case - Base Housing.stl]
2026-09-29 Rename MyKeeb Case - Foam Plate(1).step to STEP files/MyKeeb Case - Foam Plate.step
    [MyKeeb Case - Foam Plate.step]
2026-09-29 Rename MyKeeb Case - Plate(1).step to MyKeeb Case - Plate.step
    [MyKeeb Case - Plate.step]
2026-09-29 Rename MyKeeb Case - Foam Plate(2).stl to STL files/MyKeeb Case - Foam Plate.stl
    [MyKeeb Case - Foam Plate.stl]
2026-09-29 Rename MyKeeb Case - Plate(1).stl to STL files/MyKeeb Case - Plate.stl
    [MyKeeb Case - Plate.stl]
2026-09-29 Update MyKeebBOM.csv with new component data
    Replaced old BOM entries with updated ones, including new components and links.
    [MyKeebBOM.csv]
2026-09-29 Update SW78 entry in MyKeebBOM.csv
    [MyKeebBOM.csv]
2026-09-29 Add additional diode entries to MyKeebBOM.csv
    [MyKeebBOM.csv]
2026-10-03 Update MyKeebBOM.csv with new switch entries
    [MyKeebBOM.csv]
2026-10-03 Update SW78 switch link and price in BOM
    [MyKeebBOM.csv]
2026-10-03 Fix BOM header by adding 'USD' column
    Added a missing column header for 'USD' in the BOM.
    [MyKeebBOM.csv]
2026-10-03 Update MyKeebBOM.csv with new switch data
    [MyKeebBOM.csv]
2026-10-03 Update MyKeebBOM.csv with new stabilizer entries
    [MyKeebBOM.csv]
2026-10-03 Fix S5 entry in MyKeebBOM.csv
    [MyKeebBOM.csv]
2026-10-03 Update MyKeebBOM.csv to add new components
    [MyKeebBOM.csv]
2026-10-03 Update MyKeebBOM.csv with new switch details
    [MyKeebBOM.csv]
2026-10-03 Fix formatting for S5 entry in MyKeebBOM.csv
    [MyKeebBOM.csv]
2026-10-03 Update MyKeebBOM.csv with new component details
    [MyKeebBOM.csv]
2026-10-03 Modify MyKeebBOM.csv with new component data
    Updated component details and links in MyKeebBOM.csv.
    [MyKeebBOM.csv]
2026-10-03 Update Raspberry Pi Pico entry in BOM
    [MyKeebBOM.csv]
2026-10-04 Update MyKeebBOM.csv with new component links
    [MyKeebBOM.csv]
2026-10-04 Update SK6812MINI-E LED entry in BOM
    Replaced a duplicate entry for SK6812MINI-E LED with a new entry, updating the stock status.
    [MyKeebBOM.csv]
2026-10-28 Document progress on mechanical keyboard project
    Updated JOURNAL.md with detailed progress on mechanical keyboard project, including PCB design, case design, and firmware development.
2026-10-28 Rename MyKeeb.kicad_pcb to Kicad Files/MyKeeb.kicad_pcb
2026-10-28 Rename MyKeeb.kicad_sch to Kicad Files/MyKeeb.kicad_sch
2026-10-28 Fix PCB link in README.md
    Updated PCB link to point to the correct file location.
2026-10-28 Update PCB link in README.md
2026-10-31 Rename MyKeeb V2 - Top Housing.stl to STL files V2/MyKeeb V2 - Top Housing.stl
2026-10-31 Rename MyKeeb V2 - Plate.stl to STL files V2/MyKeeb V2 - Plate.stl
2026-10-31 Rename MyKeeb V2 - Base Housing.stl to STL files V2/MyKeeb V2 - Base Housing.stl
2026-10-31 Rename MyKeeb V2 - Top Housing.step to STEP files V2/MyKeeb V2 - Top Housing.step
2026-10-31 Rename MyKeeb V2 - Plate.step to STEP files V2/MyKeeb V2 - Plate.step
2026-10-31 Rename MyKeeb V2 - Base Housing.step to STEP files V2/MyKeeb V2 - Base Housing.step
2026-10-31 Rename MyKeeb.kicad_sch to Kicad V2/MyKeeb.kicad_sch
2026-10-31 Rename MyKeeb.kicad_pro to Kicad V2/MyKeeb.kicad_pro
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2026-11-01 Rename STL files/MyKeeb Case - Top Housing.stl to V1/STL files/MyKeeb Case - Top Housing.stl
2026-11-01 Rename STL files/MyKeeb Case - Base Housing.stl to V1/STL files/MyKeeb Case - Base Housing.stl
2026-11-01 Rename STL files/MyKeeb Case - Foam Plate.stl to V1/STL files/MyKeeb Case - Foam Plate.stl
2026-11-01 Rename STL files/MyKeeb Case - Plate.stl to V1/STL files/MyKeeb Case - Plate.stl
2026-11-01 Rename STEP files/MyKeeb Case - Base Housing.step to V1/STEP files/MyKeeb Case - Base Housing.step
2026-11-01 Rename STEP files/MyKeeb Case - Foam Plate.step to V1/STEP files/MyKeeb Case - Foam Plate.step
2026-11-01 Rename STEP files/MyKeeb Case - Plate.step to V1/STEP files/MyKeeb Case - Plate.step
2026-11-01 Rename STEP files/MyKeeb Case - Top Housing.step to V1/STEP files/MyKeeb Case - Top Housing.step
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2026-11-01 Update JOURNAL.md with PCB and case design entry
    Added details about PCB completion and case design progress.
2026-11-01 Fix PCB link in README
    Updated PCB link to point to the new version in Kicad_V2.
2026-11-01 Fix PCB link in README
    Updated PCB link to the latest version on KiCanvas.
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
